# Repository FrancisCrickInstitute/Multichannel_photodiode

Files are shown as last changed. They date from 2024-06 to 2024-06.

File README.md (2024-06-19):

Render

The device has 4 photodiodes and their amplification circuits. It has been designed to acquire analogue signals of different visual stimuli displayed on an LCD monitor. The information being encoded in 4 bits of information.
It could be potentially used to record grayscale but it has not been explored. The main components are the four photodiodes (Osram BPW34S) , two dual transimpedance amplifiers (Texas instruments OPA2380) and a first order low pass filter (fc = 1kHz) for each amplification circuit.

We evaluated the performance of a single channel at different frequencies 10kHz, 100kHz, 500kHz and 1 MHz

SDS00001
SDS00002
SDS00003
SDS00004

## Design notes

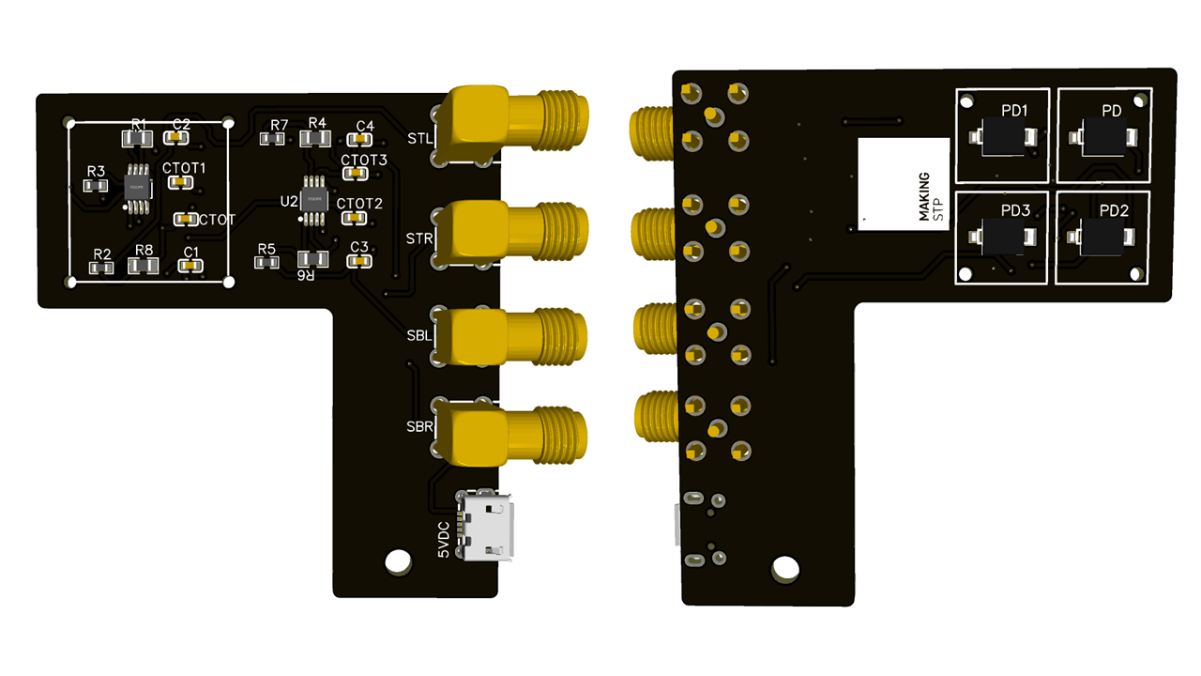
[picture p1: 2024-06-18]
Render.png

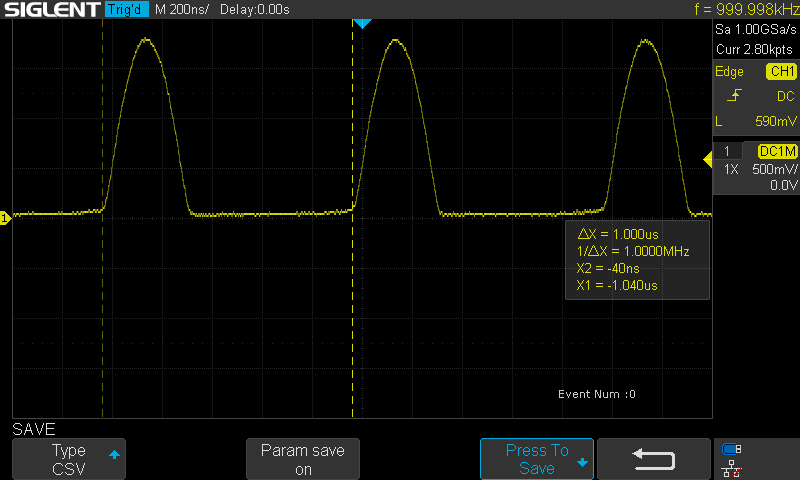
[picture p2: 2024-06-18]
Data (without the 1 kHz filter)/SDS00004.png

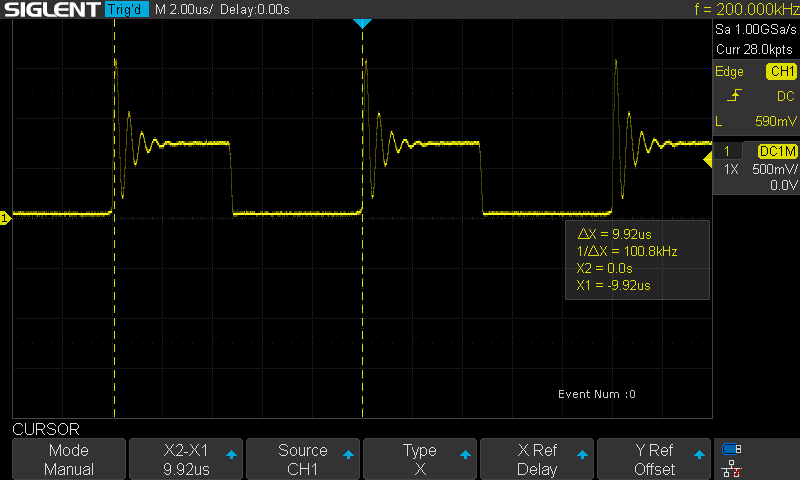
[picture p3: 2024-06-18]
Data (without the 1 kHz filter)/SDS00002.png

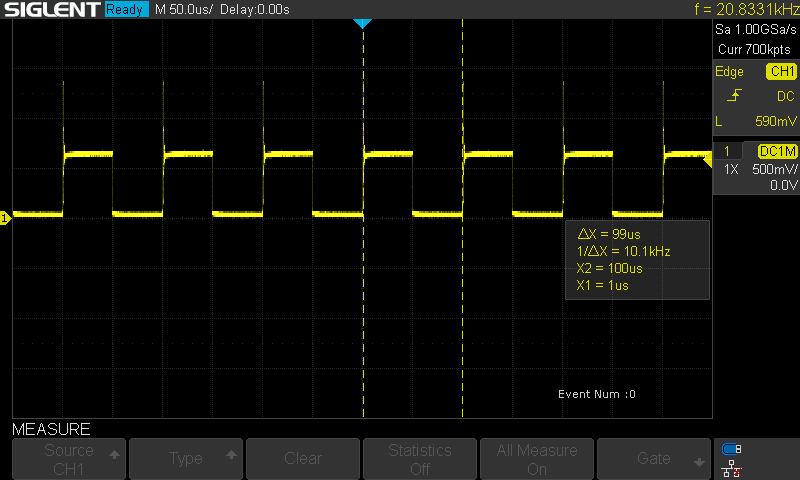
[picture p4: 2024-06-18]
Data (without the 1 kHz filter)/SDS00001.png

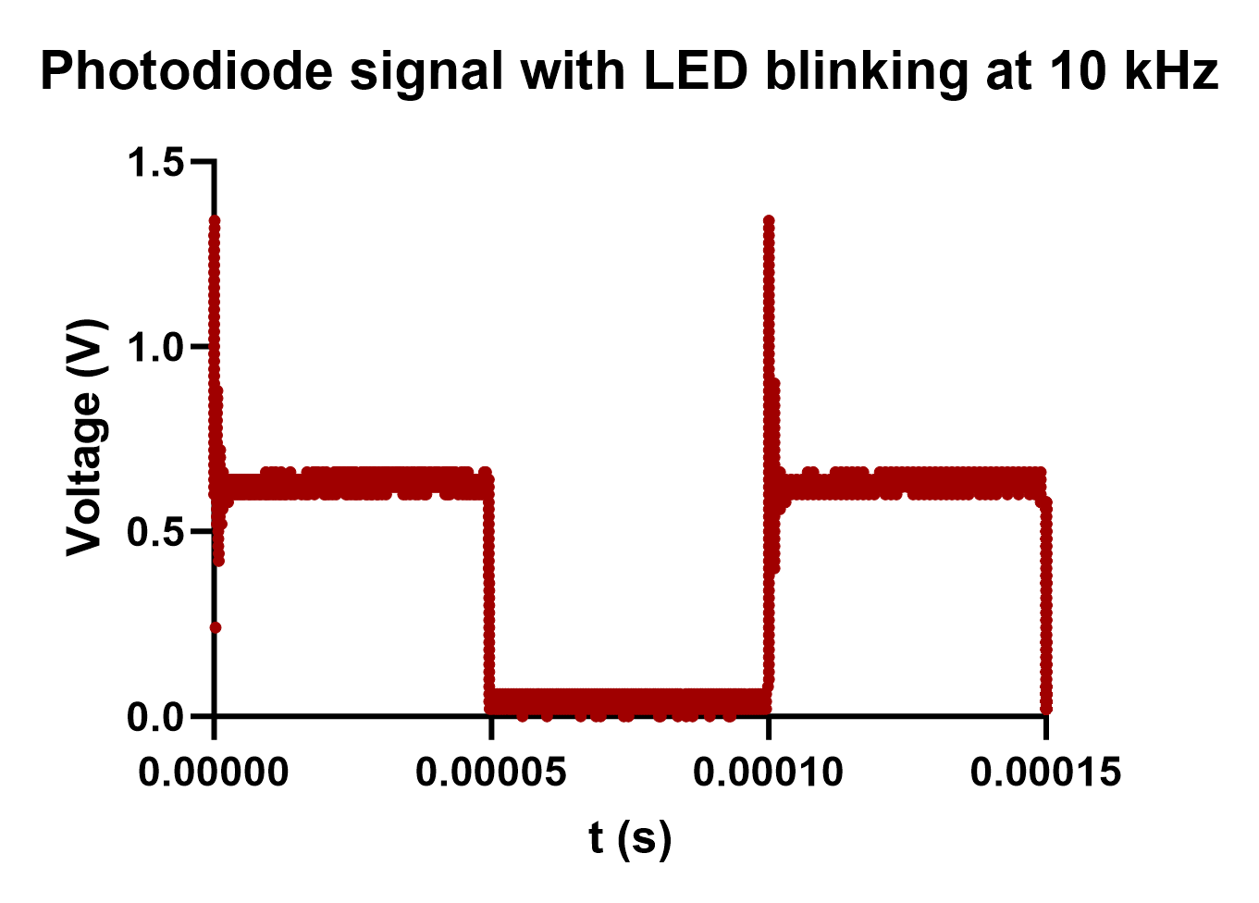
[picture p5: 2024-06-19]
Data (without the 1 kHz filter)/10 kHz.png

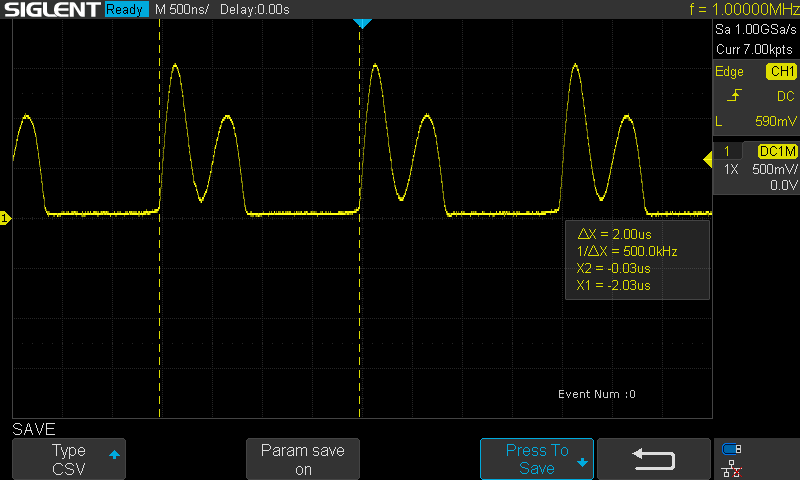
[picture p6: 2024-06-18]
Data (without the 1 kHz filter)/SDS00003.png

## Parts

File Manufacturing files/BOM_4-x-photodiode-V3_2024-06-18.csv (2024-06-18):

ID | Name | Designator | Footprint | Quantity | Manufacturer Part | Manufacturer | Supplier | Supplier Part | Price | Pins
1 | _ | PCB |  | 1
2 | 10MΩ | R1,R4,R6,R8 | R0805 | 4 | 0805W8F1005T5E | UNI-ROYAL(厚声) | LCSC | C26108 | 0.002 | 2
3 | BWSMA-KWE-Z001 | SBL,SBR,STL,STR | SMA-TH_BWSMA-KWE-Z001 | 4 |  | BAT WIRELESS(蝙蝠无线) | LCSC | C496551 | 0.417 | 5
4 | Micro USB 5P H | 5VDC | MICRO-USB_MICRO-USB-30 | 1 |  | 精拓金 | LCSC | C40946 | 0.066 | 9
5 | 100nF | C1,C2,C3,C4 | C0603 | 4 |  | YAGEO(国巨) | LCSC | C14663 | 0.002 | 2
6 | 68pF | CTOT,CTOT1,CTOT2,CTOT3 | C0603 | 4 |  | SAMSUNG(三星) | LCSC | C28262 | 0.007 | 2
7 | 1.5kΩ | R2,R3,R5,R7 | R0603 | 4 |  | UNI-ROYAL(厚声) | LCSC | C22843 | 0.001 | 2
8 | OPA2380AIDGKR | U1,U2 | VSSOP-8_L3.0-W3.0-P0.65-LS4.9-BL | 2 |  | TI(德州仪器) | LCSC | C701997 |  | 8
9 | BPW34S-Z | PD,PD1,PD2,PD3 | SENSOR-TH_BPW34S-Z | 4 |  | OSRAM(欧司朗) | LCSC | C67891 | 0.731 | 2

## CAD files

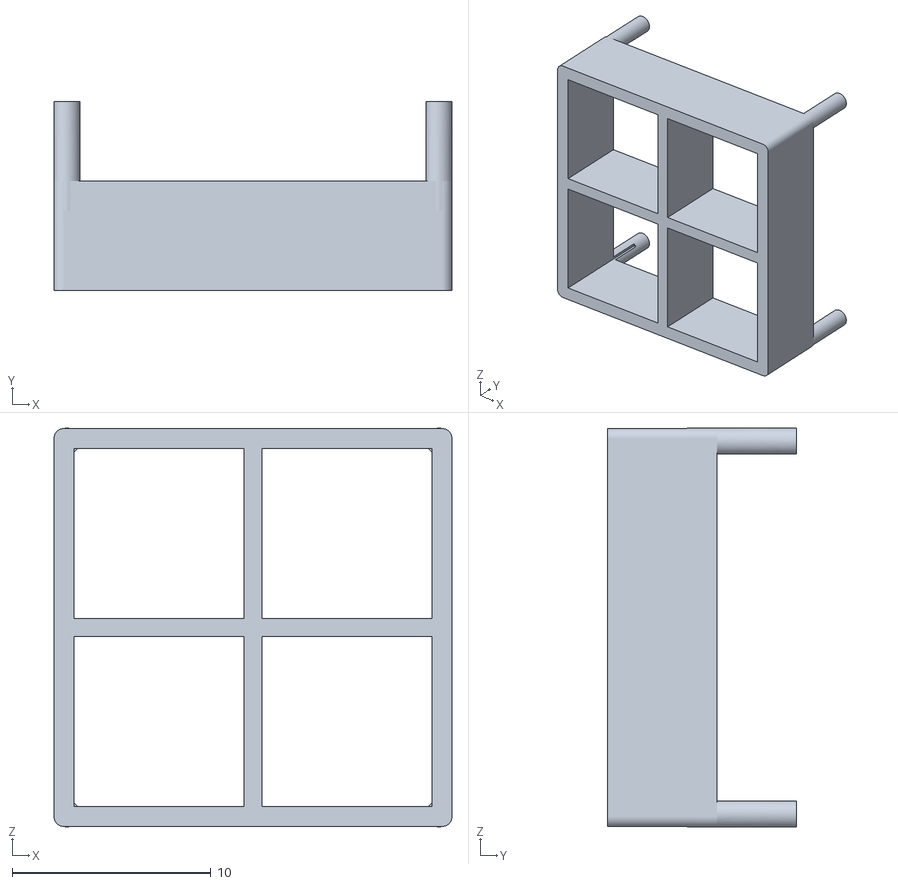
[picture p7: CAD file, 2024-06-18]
Manufacturing files/skirt.stl
20.0 x 9.50 x 20.0

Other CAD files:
Design files/skirt.ipt

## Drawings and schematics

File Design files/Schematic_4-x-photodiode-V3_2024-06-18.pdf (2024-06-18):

## Power connector

## Signal connectors

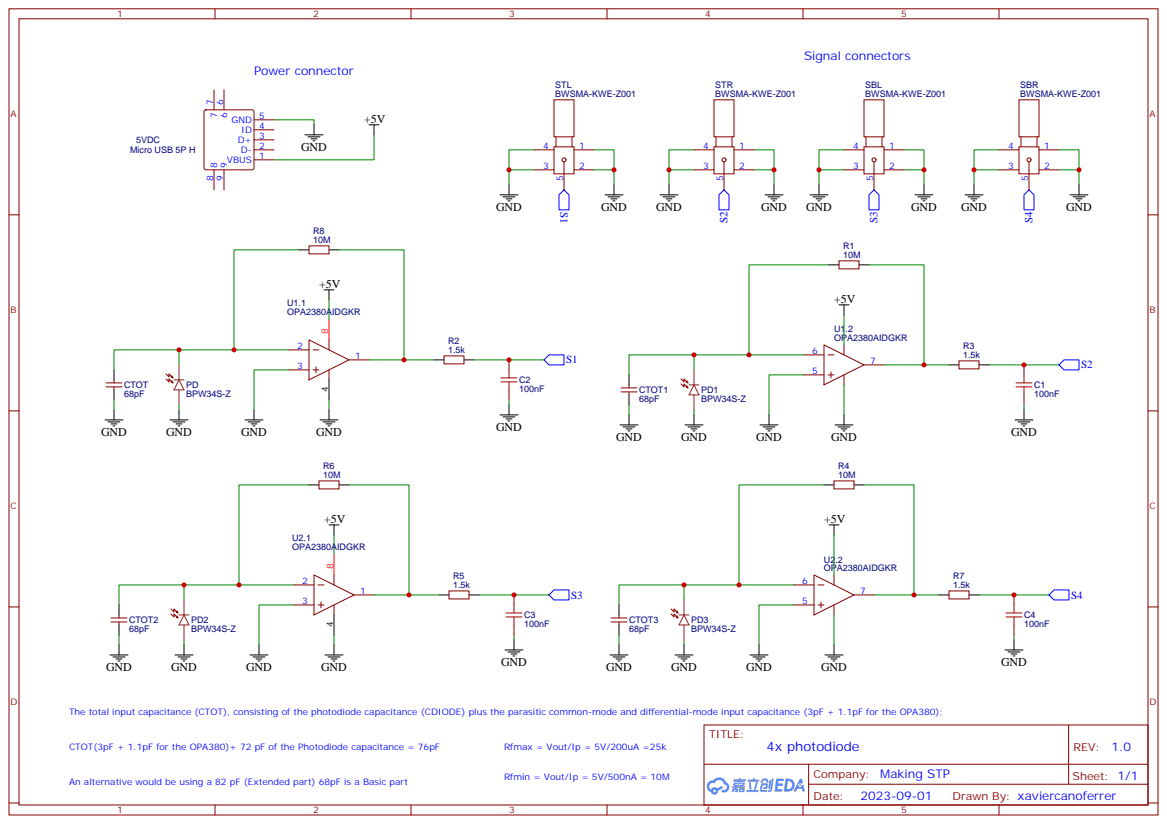
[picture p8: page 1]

The total input capacitance (CTOT), consisting of the photodiode capacitance (CDIODE) plus the parasitic common-mode and differential-mode input capacitance (3pF + 1.1pF for the OPA380);

CTOT(3pF + 1.1pF for the OPA380)+ 72 pF of the Photodiode capacitance = 76pF

An alternative would be using a 82 pF (Extended part) 68pF is a Basic part
